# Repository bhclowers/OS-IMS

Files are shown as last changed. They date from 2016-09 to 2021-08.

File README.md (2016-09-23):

# APIMS
Atmospheric Pressure Ion Mobility Design

The design files located in this repository comprise the working design files used for the atmospheric pressure ion mobility spectrometer operated at Washington State University (Dr. Brian Clowers) and Azuza Pacific University (Dr. Eric Davis). Periodic updates will be pushed as modifications are made.  A wiki will be populated for the next version of the system is constructed to provide other researchers with a detailed set of assembly instructions. 

<p align="center">
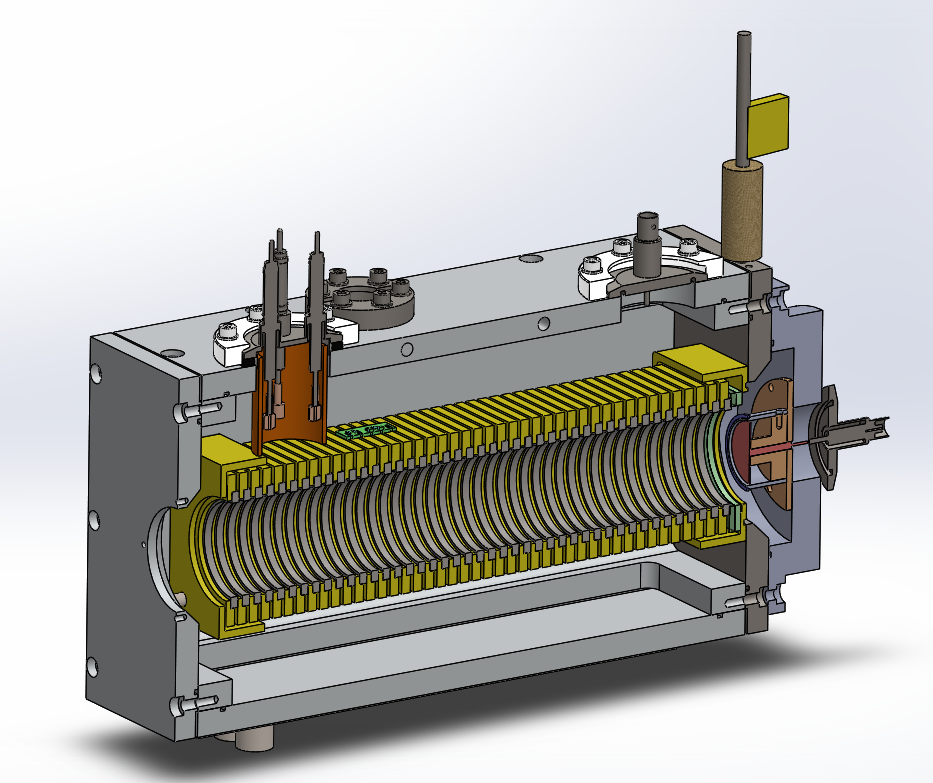
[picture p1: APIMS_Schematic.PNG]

</p>

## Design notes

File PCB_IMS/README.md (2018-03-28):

## This directory contains the latest version of the PCB IMS to be detailed in the manuscript submitted to HardwareX.  These files outline the design and assembly of a high performance, open-source Ion Mobility System

<p align="center">
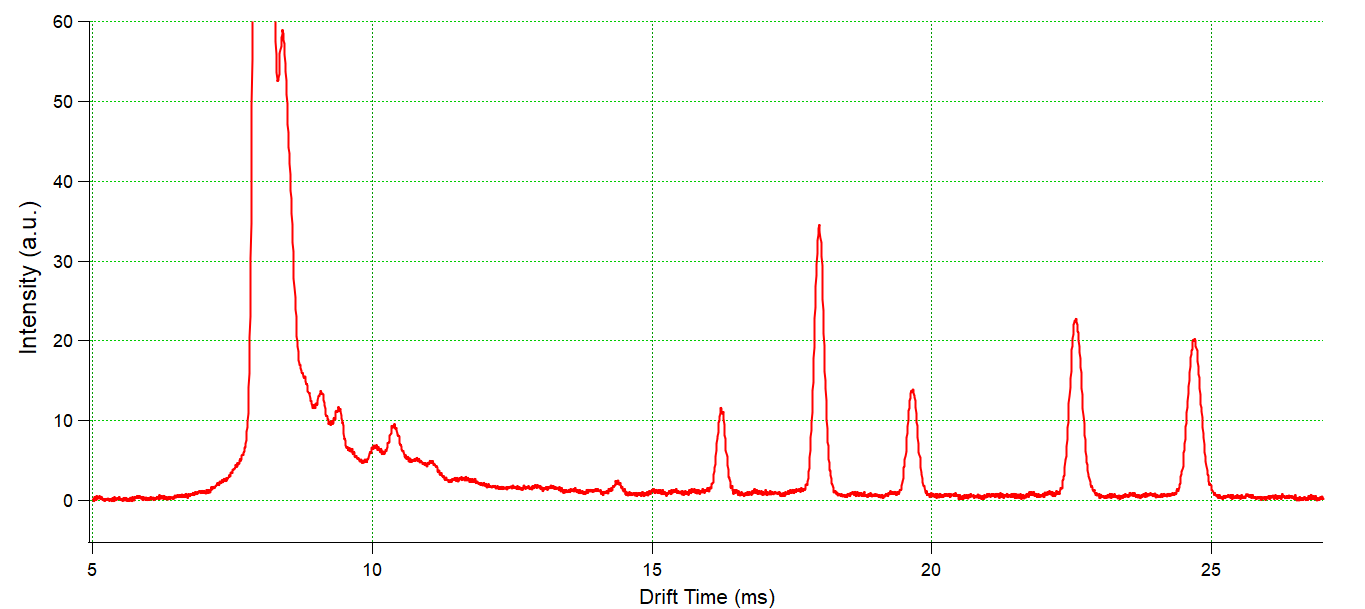
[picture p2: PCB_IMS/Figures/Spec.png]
  </p>
</center>
<p align="center">
  </p>
</center>

#### When operated as a stand-alone device, an ion mobility spectrometer (IMS) routinely offers low limits of detection (pptv-range) for gas-phase analytes even for measurement times less than a second. Mass analyzers further enhance the analytical power of IMS separations, however, high performance drift-cell IMS instruments are often highly customized, relatively large, and require extensive expertise to operate. In this work we present an optimized, low cost IMS system that leverages an easy-to-assemble ion gating structure that enables IMS spectra with resolving powers exceeding 90 for a drift cell only 10 cm in length. The IMS presented in this work consists of stacked rings divided by spacers all fabricated from printed circuit boards (PCB). The rings are connected via a slotted PCB-board containing a surface mounted voltage divider that connects directly to the ring electrodes allowing a fast and easy assembly. This highly modular design enables e.g. the realization of variable drift tube lengths or single and dual gate setups. Instead of the commonly used Bradbury Nielsen gates, the IMS is equipped with a 3-grid ion gate allowing the generation of short (<50 μs) ion packets increasing the resolving power of the instrument. 

### License

Open Source Hardware 

The PCB-IMS is an open source project by [*Tobias Reinecke*](mailto:treinecke@gmail.com) and [*Brian Clowers*](mailto:bhclowers@gmail.com).

The use, modification, and implementation of this project is goverened by the [CERN Open Hardware Licence v1.2](LICENSE).

#### Acknowledgements:
* This work was supported in part by the National Science Foundation (CHE-1506672) and DTRA (Award Number: HDTRA1-14-1-0023)
* We would also like to acknowledge the dedicated, prolific, and timeless efforts of [*Gordon A. Anderson*](https://github.com/GordonAnderson).

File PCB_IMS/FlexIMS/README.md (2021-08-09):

## The following files are to realize a flexible IMS system following the concept originally reported by Smith et al. (https://doi.org/10.1021/acs.analchem.0c01357).  These files represent the interpretation of the concept by Smith et al. but implemented at WSU.

Note: 
* Designs are currently in solidworks.  Should you not have access to this CAD platform, consider the use of OnShape for conversion to STL for printing or fabrication.
* 
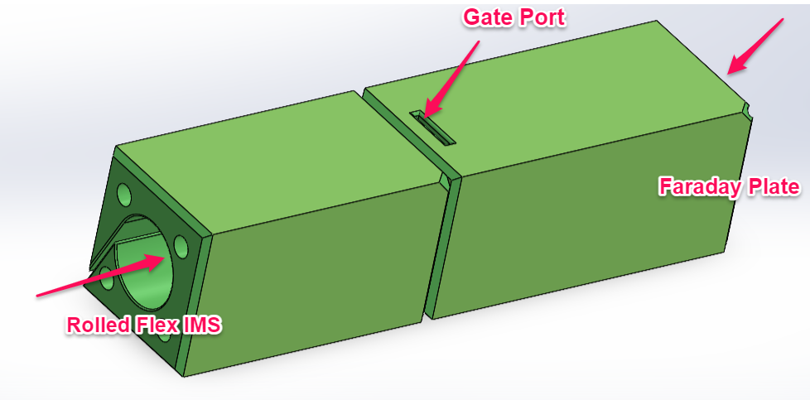
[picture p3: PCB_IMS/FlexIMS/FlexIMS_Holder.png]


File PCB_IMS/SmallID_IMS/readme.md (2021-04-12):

### When coupled with thinner pcb spacers, these electrodes can be used to generate highly uniform field in a fashion similary to the original manuscript by Reinecke and Clowers.  https://www.sciencedirect.com/science/article/pii/S2468067218300294
### For a detailed assessment, please note that the spacing and pitch ratios of electrodes is based upon the work by Bohnhorst et al. https://link.springer.com/article/10.1007/s12127-016-0202-7

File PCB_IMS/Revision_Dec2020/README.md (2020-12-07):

## Updated design files currently used in the lab. 

### We have found it useful to print out teflon spacers (usually out of 0.005" teflon from McMaster) and incorporate them into the assembly.  These help seal the chamber (yes, we've dunked an IMS like a bicycle tire) and ensure there are no leaks. For more details in this regard please see: http://www.clowersresearch.com/main/open-source-ims-initiative/

### Additionally, it is important to know that each board manufacturer will make boards with differing thickness tolerances.  It is for this reason that stacking 30 rings and spacers together may yield a scenario where the slots for the DC coupler do not align exactly.  If that is the case you may need to manually adjust the DC coupler file to make it fit to your specific board run.  Our iterative approach when ordering a large new batch of electrodes is to assemble a stack, test out the old DC coupler, and then adjust that coupler if needed and reorder.

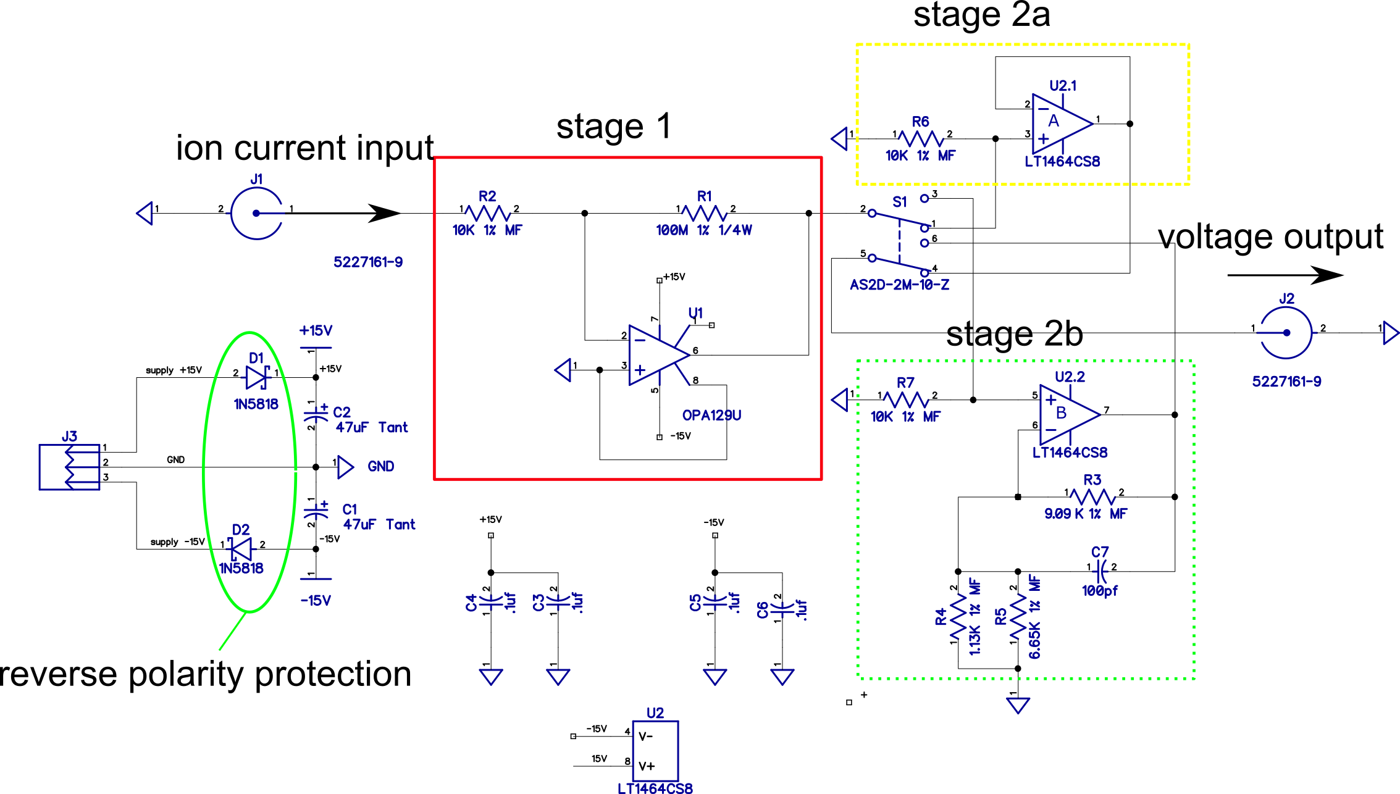
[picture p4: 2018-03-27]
PCB_IMS/Figures/schematic amp.png

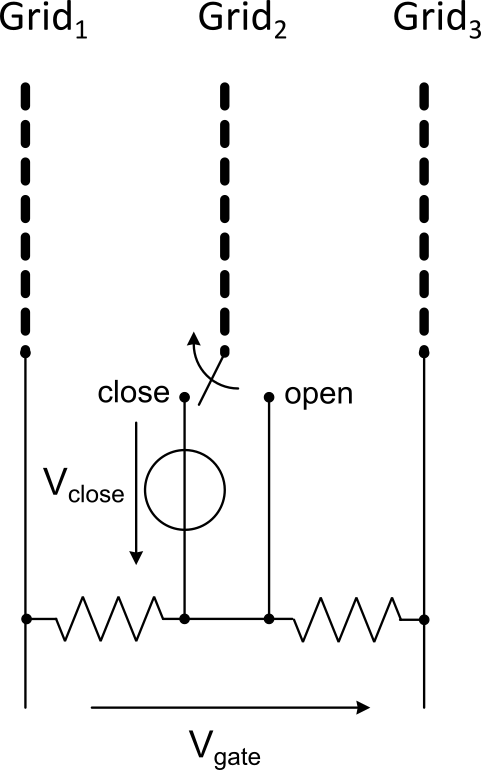
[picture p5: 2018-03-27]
PCB_IMS/Figures/schematic3gridS.png

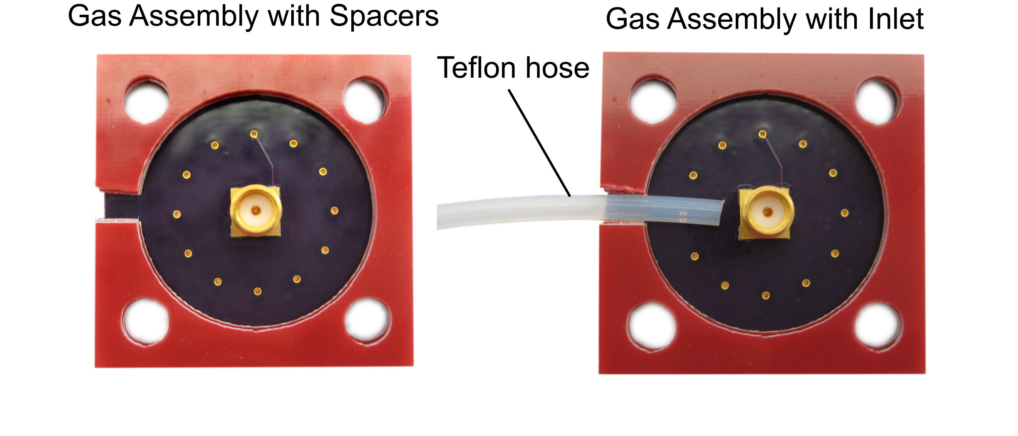
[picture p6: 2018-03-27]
PCB_IMS/Figures/DEtector-spacers-and-hose.png

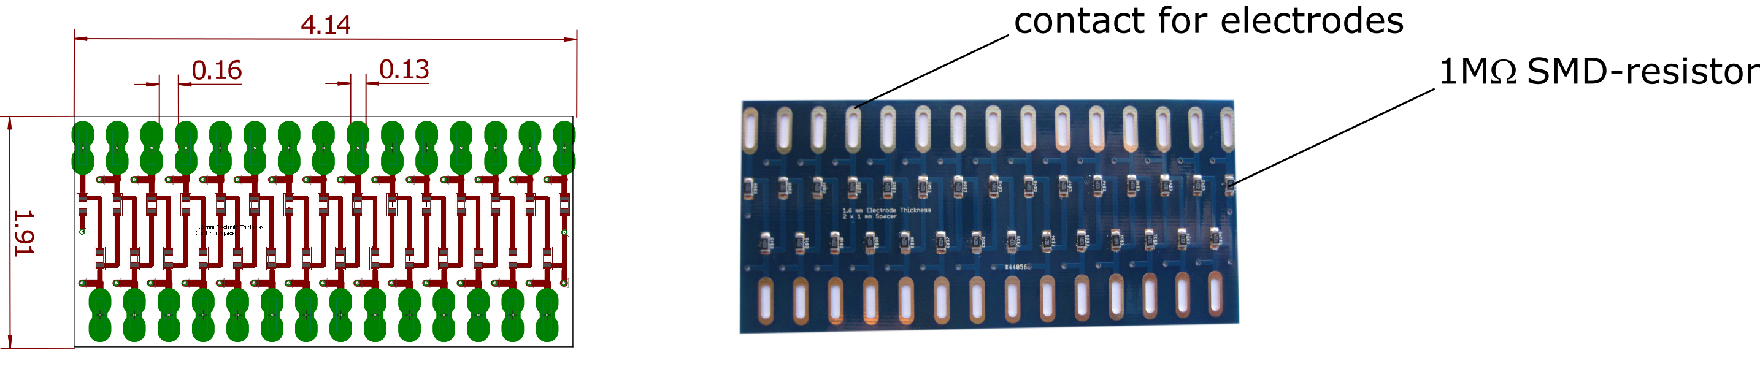
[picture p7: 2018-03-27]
PCB_IMS/Figures/top board.png

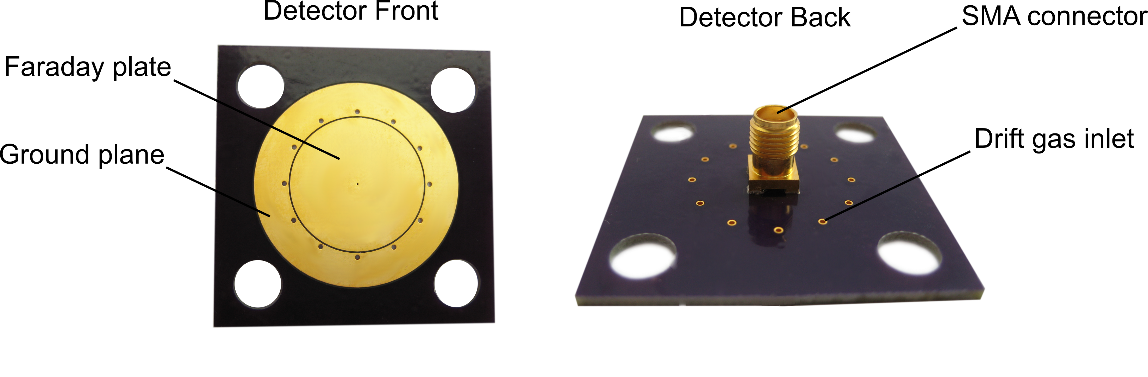
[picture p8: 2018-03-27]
PCB_IMS/Figures/Detector1.png

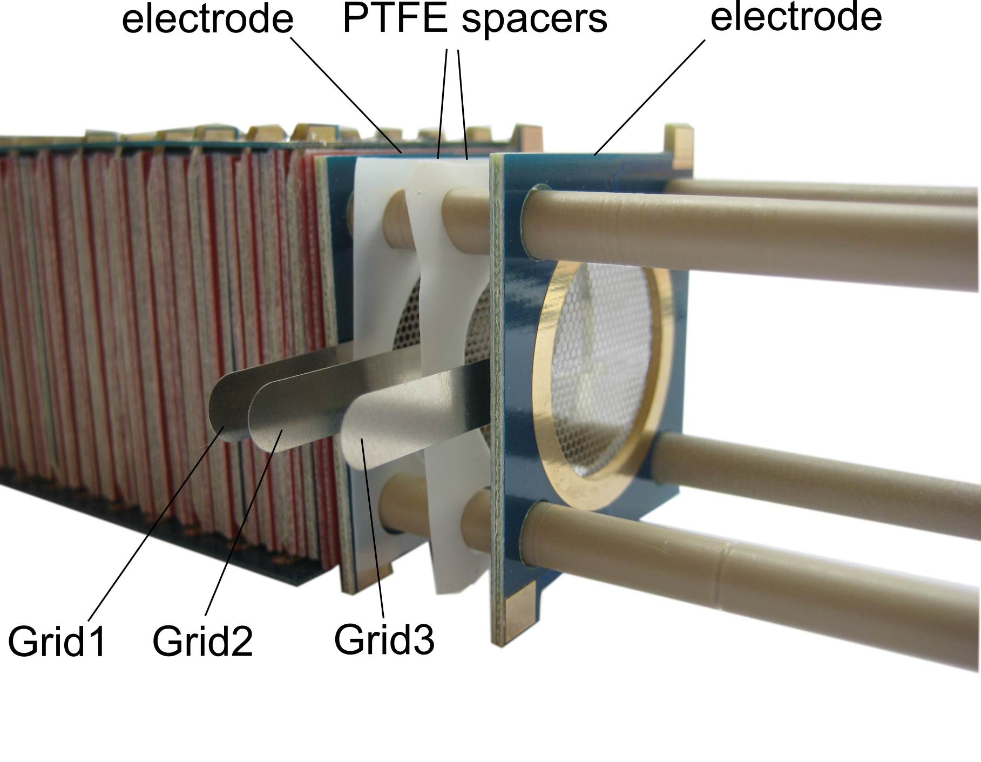
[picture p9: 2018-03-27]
PCB_IMS/Figures/Foto shutter.png

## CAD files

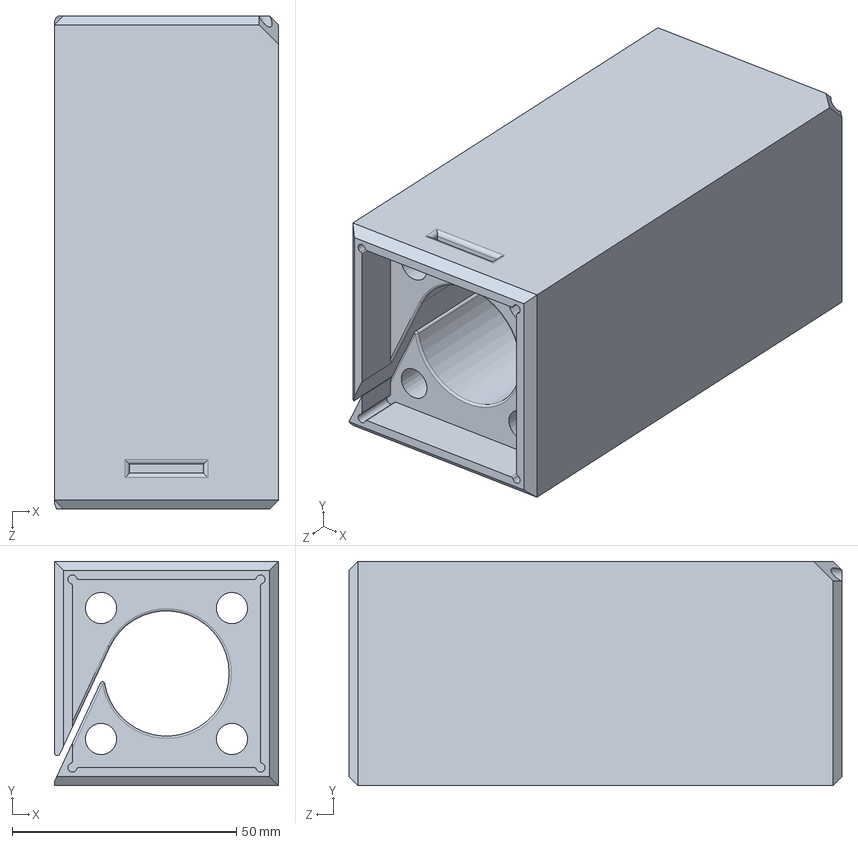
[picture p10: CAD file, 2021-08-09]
PCB_IMS/FlexIMS/Flex_PCB_Gate_Interface_v6.SLDPRT
50.0 x 50.0 x 110.0 mm

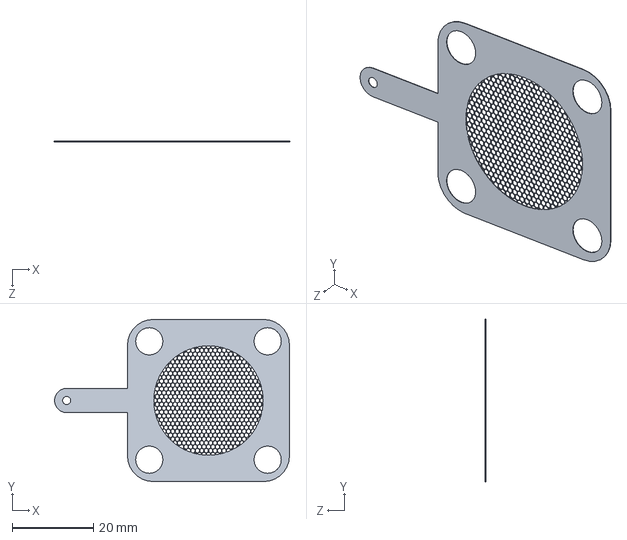
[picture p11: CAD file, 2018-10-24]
PCB_IMS/Grid_WSU_v2.SLDPRT
58.0 x 40.0 x 0.1 mm

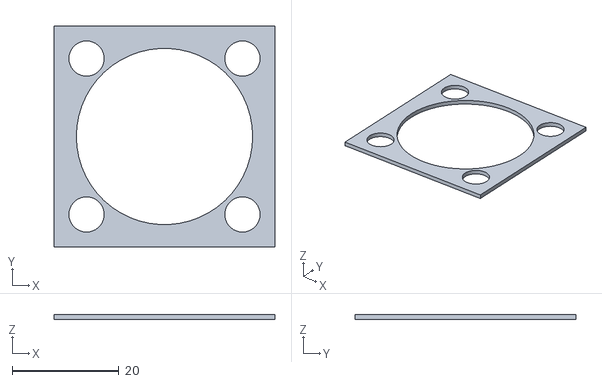
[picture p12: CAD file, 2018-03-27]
PCB_IMS/1b_Spacer.STL
41.4 x 41.4 x 1

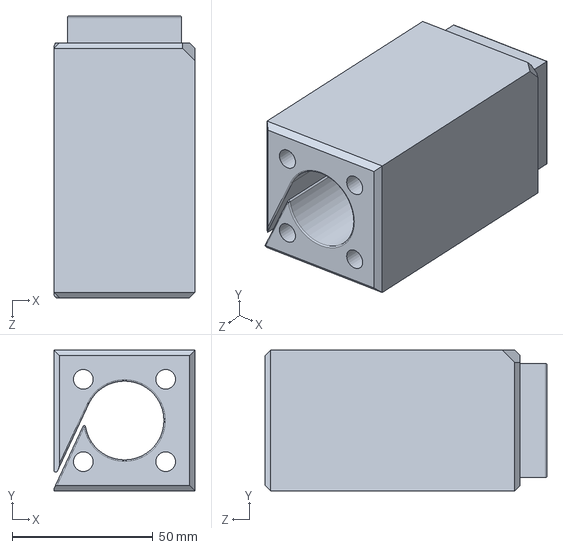
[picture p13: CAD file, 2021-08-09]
PCB_IMS/FlexIMS/Flex_PCB_Gate_Interface_v6B.SLDPRT
50.0 x 50.0 x 100.0 mm

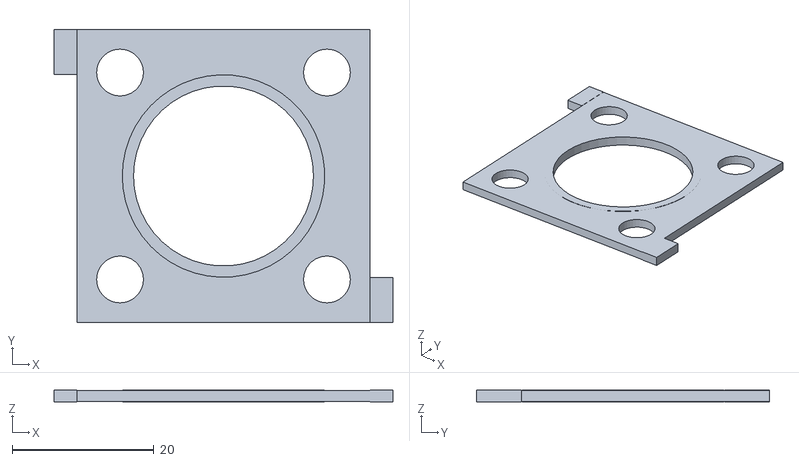
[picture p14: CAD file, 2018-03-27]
PCB_IMS/2b_Electrode.STL
47.9 x 41.4 x 1.70

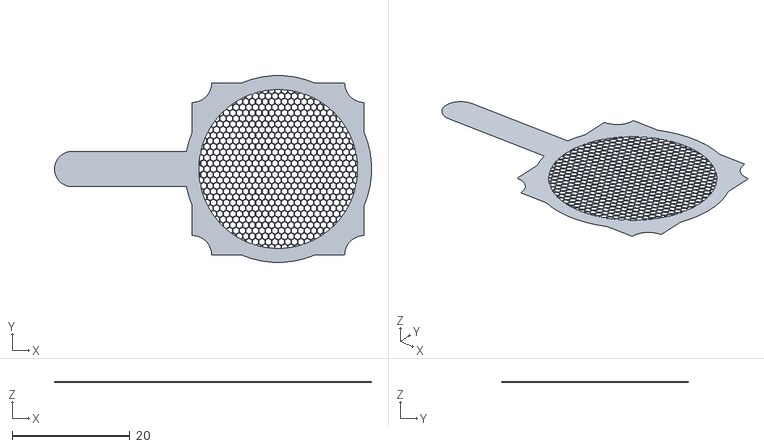
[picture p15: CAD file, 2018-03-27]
PCB_IMS/6_Grid.STL
53.9 x 31.7 x 0.1

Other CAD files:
PCB_IMS/Spacer_v1.SLDPRT
PCB_IMS/Grid WSU.SLDPRT
PCB_IMS/Electrode_v1.SLDPRT

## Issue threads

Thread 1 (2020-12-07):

1a_spacer.brd and 2a_Electodes.brd is not same as mentioned in paper.

AbidHussain70, 2020-12-07:
PCB files for spacer and Electrodes given in this repository are not same as mentioned in paper.

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

**The above pictures are from the paper.**

**While in this repo it is different.**
I open the 1a_Spacers.brd and this is how it looks,
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

**And this is the 2a_Electrodes.brd,**

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

bhclowers, 2020-12-07:
Hopefully, this will address the issue: https://github.com/bhclowers/OS-IMS/tree/master/PCB_IMS/Revision_Dec2020

AbidHussain70, 2020-12-10:
Board dimensions are not set.
This detector board Gerber file output in jlcbcb.
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

IMS_Electrode_1in_R4.brd is different, not same as paper and also no dimension. For this I can set dimension from the paper.

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

**Spacers1_25_Single.brd has no dimension.**

bhclowers, 2020-12-10:
It looks like you might not have the appropriate layers set on your cam export settings for Eagle.  You need to make sure you are exporting your mill and dimension layers appropriately.  In the future, please create a separate issue to keep things organized.

Sparkfun and Adafruit have some decent tutorials on how to set this.  Also, Eagle has a layer preview setting that can be useful.

https://learn.sparkfun.com/tutorials/designing-pcbs-advanced-smd/gerber-generation

Your board should look something like this:
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

Good luck!

Closed 2020-12-10.

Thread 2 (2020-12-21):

Amplifier PCB circuit is not labelled.

AbidHussain70, 2020-12-21:
I2V_Rev4.brd file provided in your repository has no labelling for the components.

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

bhclowers, 2020-12-21:
For some reason these were removed.  Feel free to add them back in.  Unfortuantely, I don't have the bandwidth right now to make this happen. The good news is that the parts have not really changed in any way from the older gerber files released.

Closed 2020-12-21.

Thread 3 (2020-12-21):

BOM for amplifier (I2V_Rev4.brd) missing.

AbidHussain70, 2020-12-21:
There is no BOM for I2V_Rev4.brd PCB.

bhclowers, 2020-12-21:
Board components are listed through the properties tab.

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

Closed 2020-12-21.

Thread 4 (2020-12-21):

IMS_Electrode_1in_R4.brd board has one electrode on each.

AbidHussain70, 2020-12-21:
IMS_Electrode_1in_R4.brd has one electrode on each side while in the paper both electrodes are on one side of the PCB circuit.
My Question is Does it will effect the assembly or not? If not I will use this circuit board.

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

bhclowers, 2020-12-21:
In the paper we were aiming to use the DC Coupler to hold the electrodes with solder on the top and the bottom with electrodes on both sides.  However, we noticed that doing so requried additional insulating considerations as the high voltage would now be on both sides of the board.  Moreover, the compression rods do a pretty decent job of holding things together.  For these reasons, we nixed the second electrode. Hope that clears it up.

Closed 2020-12-21.

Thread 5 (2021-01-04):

10-12kV high voltage source should be DC/which power source you used?

AbidHussain70, 2021-01-04:
What kind of power supply will work good for IMS?
Power supply source should be DC or can I use circuit made from flyback transformers (relatively cheap option). I noticed that circuit with flyback transformer add noise at higher voltage?

AbidHussain70, 2021-02-07:
I order[ EMCO DC–HV DC Converters](https://www.digikey.com/en/product-highlight/x/xp-power/dcdc-converters-emco)
and also I got one switching power supply (3kV-18kV) from Chinese vendor, Chinese one is under 100 dollars. Currently I have 100x oscilloscope probe and I can test maximum 5kV signal with my oscilloscope.
I will order 1000x probe and I will attached the results here once I check the output fluctuation of the power supply.

bhclowers, 2021-03-10:
Be mindful of the power supplies that are unregulated.

AbidHussain70, 2021-03-15:
I checked the noise of HV, which I bought from Chinese Vendor, peak to peak noise is between 1-2%.
With 6.4KV it gives almost 80-100V peak to peak noise.
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

**Note: Oscilloscope probe is 1000x.**

bhclowers, 2021-03-15:
As I mentioned, using an unregulated supply can pose a challenge.  It is also important that you check the ripple when the power supply is connected to a load (i.e. the IMS cell or some other resistive divider). Finally, you may consider using a HV capacitor to ground (but make sure it is large enough for the voltage) as this may reduce the ripple.

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

AbidHussain70, 2021-03-24:
I received HV capacitor today, I will put this capacitor in parallel and  I will test the output of the HV power source.

Closed 2023-10-29.

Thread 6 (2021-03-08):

corona needle should be connected to the SMA connector?

AbidHussain70, 2021-03-08:
In the paper, in section 6, corona needle placement is described briefly. I paste that portion of paper below:

 _**For the measurement of the corona-ionizationspectrum (Fig. 17(a)), a home built corona needle was placed centric and in close proximity to the first ring of the desolvationregion and connected to an electric potential of 14.5 kV. Then, sampled headspace from 2,4-lutidine was applied via a PEEK capillary which is connected to a gas tight syringe containing the sample. The capillary sample inlet is shown inFig. 16. Theassembly is similar to the assembly of the drift gas inlet described above, while using a 0.01 ID/0.062 OD PEEK capillaryinstead of the Teflon hose. Due to the smaller diameter of the capillary compared to the Teflon hose, only one (middle) ofthe three spacers used has a cut out. It should be noted that a range of gas-phase sample introduction mechanisms maybe implemented

(PDF) Implementation of a Flexible, Open-Source Platform for Ion Mobility Spectrometry. Available from: https://www.researchgate.net/publication/325255050_Implementation_of_a_Flexible_Open-Source_Platform_for_Ion_Mobility_Spectrometry [accessed Mar 08 2021].**_

### My Question is,
Should I attach the corona needle into SMA connector or should I palace it at a distance?

bhclowers, 2021-03-10:
I'm not sure about your connection.  SMA is a signal connector and not a HV connector.  The tip of the corona needle should be placed a couple of mm inside the desolvation/reaction region.

Something like this:

IMS Rings                 |   |   |   |   |   |

Corona Needle ------>                             Detector

IMS Rings                 |   |   |   |   |   |

AbidHussain70, 2021-04-13:
This is how I made the final assembly. For the needle I add a support to make it fixed.
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

Closed 2023-10-29.

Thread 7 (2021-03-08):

Corona needle requires separate power source?

AbidHussain70, 2021-03-08:
The first ring of the desolvation region should be connected to an electric potential of 11.5 kV via a high voltage power supply. and corona needle needs a power supply with almost same potential.

Can I use same power supply or should I use separate power source?

bhclowers, 2021-03-10:
Yes, the corona supply will require a separate supply.  If you have access to a floating supply, you can float the corona on top of the drift voltage.  However, care should be taken to ramp the corona and drift voltages up simultaneously.  It is important to make sure the voltage differential between the corona and the IMS drift potential isn't too large as to cause a catastrophic arc.

Closed 2023-10-29.

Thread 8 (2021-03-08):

Can I use Teflon Hose for gaseous inlet?

AbidHussain70, 2021-03-08:
Can I use the same Teflon hose--used in draft gas inlet, for gaseous inlet or should I use 01 ID/0.062 OD PEEK capillary mention in the paper?

bhclowers, 2021-03-10:
If you are referring talking about the drift gas inlet, 0.062 inlet might be a little small for 300 mL/min.  However, it should work.  As for a sample inlet, the volume of this tube should be ok. However, the smaller ID for the sample inlet, the fast the sample will arrive into the reaction region.

AbidHussain70, 2021-03-24:
I used 1.6mm inner diameter Teflon hose for Drift gas inlet and I ordered 0.25 mm PEEK capillary for sample injection.
Thanks

Closed 2021-03-24.

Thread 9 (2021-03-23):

Final Assembly!

AbidHussain70, 2021-03-23:
I finished the assembly of OS-IMS,

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

This is my final assembly, I have few questions before I start testing the device.

**1) I used a conductor needle (200 micron) for sample injection, is it fine or should I used non-conductor material like PEEK capillary, the one you used in your paper?
2) I put three shatter grid between drift and desolvation region. And the last electrode of both drift and desolvation region is connected to the first and third grid respectively. I put insulator between first and second grid and second and third grid. Is this configuration correct or should I make some changes?
3) Should I use floating power source, by floating I mean should I use just positive terminal of the HV power source?
If I need to connect the negative terminal of the HV source, which point should I attach the negative terminal?**

AbidHussain70, 2021-03-24:
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

For grid shatter what I understood is, first and last grids are in direct contact with electrodes. And I put spacers between 2nd and 3rd.
I read all the links but I need to know above points (which I mentioned in the issue). Can you please guide me?

bhclowers, 2021-04-10:
The sample injector looks like it is metal. If that is the HV end, you need to address that issue.  A metal needle located at the HV end cannot be floated.  It will arc.  Additionally, you need to make sure there are insulating spacers (i.e. teflon or kapton) between the grids.  The grids should not be touching each other in any fashion when assembled.

AbidHussain70, 2021-04-12:
I changed the sample injector to a capillary tube (200um).  And I will put a common ground (big aluminum plate), for attaching all the ground terminals.

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

Closed 2023-10-29.

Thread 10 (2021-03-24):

The aperture grid is etched stainless steel grid? And how to connect?

AbidHussain70, 2021-03-24:
In the paper you mentioned that drift tube is terminated with aperture grid,
following lines are from your paper.

__To shield the detector from an image current induced from the approaching ion cloud, the drift tube is terminated with an aperture grid which is directly placed on the last electrode, followed by 1 spacer and finally the detector. The aperture grid is connected via a 500 k resistor to ground, as shown in Fig. 12. To stabilize the voltage on the aperture grid, it is advantageous to add an additional capacitor (we used 0.22mF) in parallel to the resistor._

I have few questions;

1) What is aperture grid? it is etched stainless steel grid?
2) How to connect Detector to drift tube? Can you please explain this figure?
its from your paper.

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

3) Where should I connect the ground terminal of the supply (common ground)?

AbidHussain70, 2021-03-31:
Hi,
can you explain?

bhclowers, 2021-03-31:
You need to ground your supply as specified by the manufactuer.  I would ground that grid to the same ground as your amplifier.  The grid is a wire set or the etched grid as specified in the paper.  The electronic diagram as depicted is correct. I'm not sure how else describe it other than through a schematic.

AbidHussain70, 2021-04-01:
Thanks for explanation.
Electronic schematic is correct but the missing part is the common ground (for negative terminal) for all the setup. Schematic is just for shutter grid part it does not say any thing about the whole circuit (setup). In the setup we have to use 4 power sources, one for Amplifier, one for Pulser, one HV source for ESI and one HV for electrodes. I could not find any explanation for ground terminal (negative terminal).

From your explanation I will connect shutter grid' ground (negative terminal) with amplifier' ground (negative terminal).

Closed 2021-03-31.

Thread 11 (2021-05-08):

Capillary tube for sample injection got fire when I turned the power source On!!!

AbidHussain70, 2021-05-08:
**The capillary tube caught fire. Below is the picture of the setup.**
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

**Here is gif file of the fire.**
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

**I used same brand power supply. And voltage was just 4KV on both sources.
I did not connect the pulser circuit for this initial test.**

Can you please point out the problem, I spent a so much resources on this project.
Thanks

bhclowers, 2023-10-29:
Please consult with someone familiar with high voltage electronics.  This looks dangerous. There is no time when current for the high voltage applied to this system should exceed a single digit mA. A bbq lighter is a good place to start to generate some ions. https://www.amazon.com/Rechargeable-Electric-Flexible-Flameless-BBQ%EF%BC%88Blue%EF%BC%89/dp/B07PKS6D8K?th=1

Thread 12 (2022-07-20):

Getting some errors while opening eagle files

afarahan, 2022-07-20:
Hello,

I am getting this error (Line 9, column 122: This is not an eagle file) while opening eagle files, almost the same thing happens for all .brd files. May you please let me know how I can figure out this problem?

Many thanks

bhclowers, 2023-10-29:
Eagle is no longer supported. I will make an effort to upload a new KiCad file.

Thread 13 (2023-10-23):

Should the opening and closing performance of the tristate ion shutter be tested at the ms level?

kbdydd, 2023-10-23:
I want to test the opening and closing performance of the tristate ion shutter. When testing the opening or closing time of the shutter, should the opening and closing time be at the ms level?

dkayser, 2023-10-23:
When I tested I built a simple particle-based controller where I could change the gate opening time between 500 and 150 micro seconds by pressing a button. 500uS for seeing if there is anything there, and then 150uS to get sharper peaks. Unless you work in vacuum you probably do not need faster gate open times.

bhclowers, 2023-10-29:
Dirk is correct. Even a modulation duty cycle of 50% should show you very broad on/off cycling of the ions. Depending on the performance of the amplifier you are using, you can have a period of 50 ms or more with a 50% duty cycle. You are looking for broad swings before tightening the gate pulse width. Amplification should be around 10^9 V/Amp and a target rise time of 30 us or so. Remember you are unlikely to see a signal with a single pulse as the system will be quite noisy. Multiple averages will be needed to reduce the random noise and reveal a peak.

kbdydd, 2023-10-30:
> When I tested I built a simple particle-based controller where I could change the gate opening time between 500 and 150 micro seconds by pressing a button. 500uS for seeing if there is anything there, and then 150uS to get sharper peaks. Unless you work in vacuum you probably do not need faster gate open times.

Thank you for your answer
In this system, I used a vacuum ultraviolet lamp as the ionization source with a drift voltage of only 3KV. However, I encountered some problems while testing the shutter;
(1) When I apply a 130V pulse to the tristate ion shutter, a phenomenon similar to high-voltage breakdown occurs at the position of the shutter, with electric sparks accompanied by a sizzling sound. However, I am certain that the shutter is completely insulated from the electrode and the three shutters (using a spacer made of tetrafluoroethylene, with a thickness of 0.3mm)

(2) During the testing (with the shutter open), the signal baseline of this system was very strange. I used an amplifier with a gain multiple of 10 ^ 10V/Amp, but its initial baseline was -80pA. Using acetone as the sample for injection, the measured signal unexpectedly rose to 130pA, which is completely opposite to the report in the literature.

(3) The shutter seems to be not working; When I connect the shutter to the pulse generator, the initial baseline of this system directly rises to the 130pA position in question (2). Afterwards, even though I inject the sample, the detector does not generate any signal until I disconnect the pulse generator from the shutter, and even when I touch the wire connected to the shutter, its baseline will rise to 130pA, so that I cannot truly observe whether the shutter is working.

(4) When the system baseline rises to 130pA, disconnect the pulse generator from the shutter. It takes several minutes for the baseline to decrease to -80pA, and the descent is very slow, looking very much like a capacitor charging and discharging.

(5) Should the negative electrode (ground) of the shutter pulse generator be connected to the negative electrode (ground) of the system high voltage (voltage applied to the solvent and drift regions)? Or connect the negative electrode (ground) of the shutter pulse generator to the middle of the two resistors on the three shutters mentioned in the literature?

My thoughts on these issues;
For question (1), is it the reason for the close distance between the shutters?
For questions (2), (3), and (4), does the electric field in the solvent or drift region affect the electrons in the metal shutter, resulting in the shutter not working?

kbdydd, 2023-10-30:
> Dirk is correct. Even a modulation duty cycle of 50% should show you very broad on/off cycling of the ions. Depending on the performance of the amplifier you are using, you can have a period of 50 ms or more with a 50% duty cycle. You are looking for broad swings before tightening the gate pulse width. Amplification should be around 10^9 V/Amp and a target rise time of 30 us or so. Remember you are unlikely to see a signal with a single pulse as the system will be quite noisy. Multiple averages will be needed to reduce the random noise and reveal a peak.

Thank you very much for your explanation. When verifying Mr. Drik's ideas, I encountered some problems. If you have time, I hope you can help me answer them. Thank you.

dkayser, 2023-10-31:
>  (1) When I apply a 130V pulse to the tristate ion shutter, a phenomenon similar to high-voltage breakdown occurs at the position of the shutter, with electric sparks accompanied by a sizzling sound. However, I am certain that the shutter is completely insulated from the electrode and the three shutters (using a spacer made of tetrafluoroethylene, with a thickness of 0.3mm)

Maybe high humidity? Stacked drift tubes are very hard to get air tight, try FKM gaskets and run a pressure check with the drift tube under water at 1,5 Bar or so. PTFE gaskets are too hard and seal much worse. No air should escape or you will ruin your ionization. You need to dry all gases with 3A and 4A mol sieve, and activated coal helps if you build an internal air loop. It makes a huge difference.

Also electrode hole size and electrode distance are related.

Maybe sharp edges on the shutter grids from manufacturing? Do the gates bend inwards when you apply pressure from bolting the drift tube?

> (2) During the testing (with the shutter open), the signal baseline of this system was very strange. I used an amplifier with a gain multiple of 10 ^ 10V/Amp, but its initial baseline was -80pA. Using acetone as the sample for injection, the measured signal unexpectedly rose to 130pA, which is completely opposite to the report in the literature.

How much did you inject? How much sampling are you doing (try 512x)? Or are you just measuring ion current? In that case measure the ion current of your source before injecting sample. While your at it, check whether your gate voltage is sufficient.

Regarding your other questions:
- There are many different approaches to connecting a tri state grid. And even more failure modes. Maybe your voltages are not well regulated? Does your signal generator provide enough current for driving your gate capacitance?
- Do not underestimate how much the gas preparation makes a difference. Very dry and airtight is what you want.

==> Figure out all high voltage discharges first. There should be no sizzling sounds, let alone sparks.
==> Check for air ingress, especially near the ionization region. Check if you overtighten the bolts, get FKM gaskets or O-Rings
==> Build a simple setup with your transimpedance amplifier to verify ion current

Good luck!

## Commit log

2018-03-27 Add files via upload
    Upload of files to support manuscript
    [1a_Spacers.brd, 1b_Spacer.STL, 2a_Electrodes.brd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]
2018-06-20 Included slot library
    [3_electrode alignment board.brd]
2018-10-24 Updated Files
    The DC Coupler has been updated to include a modified slot design (no bottom trace) and new grid design that ensures effective alignment.
    [CouplerDC_R12_Teflon.brd, Grid_WSU_v2.SLDPRT]
2020-11-17 Added smaller electrode board and spacers
    [CouplerDC_R12_Teflon.brd, IMS_Electrode_1in_R4.brd, Spacers1_25_Single.brd]
2020-12-07 Updated Design Files 2020
    [CouplerDC_R12_Teflon.brd, Detector_v8.brd, I2V_Rev4.brd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]
2020-12-07 New info on teflon spacers.
